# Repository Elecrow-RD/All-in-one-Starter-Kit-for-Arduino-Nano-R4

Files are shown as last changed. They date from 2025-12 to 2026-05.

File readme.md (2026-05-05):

## Menu
### 1, Product picture
### 2, Product version number
### 3, product information
### 4, Use the driver module
### 5,Quick Start
### 6,Folder structure.
### 7,Pin definition

### 1, Product picture

Crowpanel Advance ESP32 HMI AI Display

#### 2, Product version number

| | Hardware | Software | Remark |
| ---- | --- | --- | --- |
| 1 | V1.0 | V1.0 | latest |

### 3, product information

| Main Processor | Arduino NANO R4 |
| --- | --- |
| CPU/SoC | RA4M1(Arm® Cortex-M4®) |
| System memory | RAM32KB |
| Storage | Flash 256 kB |
| Bluetooth | None |
| WiFi | None |
| Interface | TYPE-C interface, I/O pins/sockets, Crowtail interface |
| Button | Reset |
| LED indicator light | Reset indicator light, power indicator light |
| Power input | 5V input charging |
| Shell material | PP (non-toxic) |
| Size | 195\*170*46（mm） |
| Net Weight | 415g |
| Operating temperature | 0°C to 60°C |
| Storage temperature | 0°C to 60°C |

### 4, Use the driver module

| Name | dependency library |
| --- | --- |
| IRremote | Arduino-IRremote-master <br />version: 4.5.0 |
| LSM6DS3  | Arduino_LSM6DS3-master<br />version=1.0.3 |
| BH1750 | BH1750<br />version: 1.3.0 |

### 5,Quick Start
### Arduino IDE starts

1.Download the library files used by this product to the 'libraries' folder.

C:\Users\Documents\Arduino\libraries\



2.Install the NANO R4 development board and open the program files

Arduino_NANO_R4-2

3.Open the code configuration environment and burn it

Arduino_NANO_R4-4

### 6,Folder structure.

|--Eagle_SCH&PCB: Contains **Eagle CAD** schematic (`.sch`) and PCB layout (`.brd`) files. These are used for circuit design and PCB manufacturing.

|--lesson_code: Provides  code and projects to demonstrate how to use the hardware and libraries. These examples help users get started quickly.

|--libraries: Includes necessary libraries required for compiling and running the project. These libraries provide drivers and additional functionalities for the hardware.

### 7,Pin definition

#### Sensor / Module List

| No.  | Sensor / Module Name | Quantity | Notes | nano pin |
| ---- | --- | --- | --- | --- |
| 1 | Temperature & Humidity Sensor | 1 | | A4/SDA<br />A5/SCL<br />I2C  ADDRESS:0X38 |
| 2 | Button | 3 | | A3_KEY |
| 3 | Ultrasonic Ranging Sensor | 1 | | D7_US_ECHO<br />D6_US_TRIG |
| 4 | Light Sensor | 1 | | A4/SDA<br />A5/SCL<br />I2C  ADDRESS:0X5C |
| 5 | Linear Potentiometer | 1 | | A0_ROTARY |
| 6 | LED (Red + Yellow + Green) | 3 | Red + Yellow + Green | ~D5_LED_R<br />~D10_LED_Y<br />~D11_LED_G |
| 7 | Buzzer | 1 | | D3_BUZZER |
| 8 | LCD Display | 1 | | A4/SDA<br />A5/SCL<br />I2C  ADDRESS:0X27 |
| 9 | Infrared Remote | 1 | Includes remote controller | D2_IR_R |
| 10 | Relay Module | 1 | | D4_RELAY |
| 11 | Servo Motor | 1 | | D9_SERVO |
| 12 | Sound Sensor | 1 | | A1_SOUND |
| 13 | 3-Axis Accelerometer | 1 | | A4/SDA<br />A5/SCL<br />I2C  ADDRESS:0x6B (pin SDO is logic High) |
| 14 | PIR Motion Sensor | 1 | | A2_PIR |
| 15 | Soil Moisture Sensor | 1 | Separate probe, 4-wire connector | A7 |
| 16 | 4-Digit Display | 1 | | A4/SDA<br />A5/SCL<br />I2C  ADDRESS:0X70 |

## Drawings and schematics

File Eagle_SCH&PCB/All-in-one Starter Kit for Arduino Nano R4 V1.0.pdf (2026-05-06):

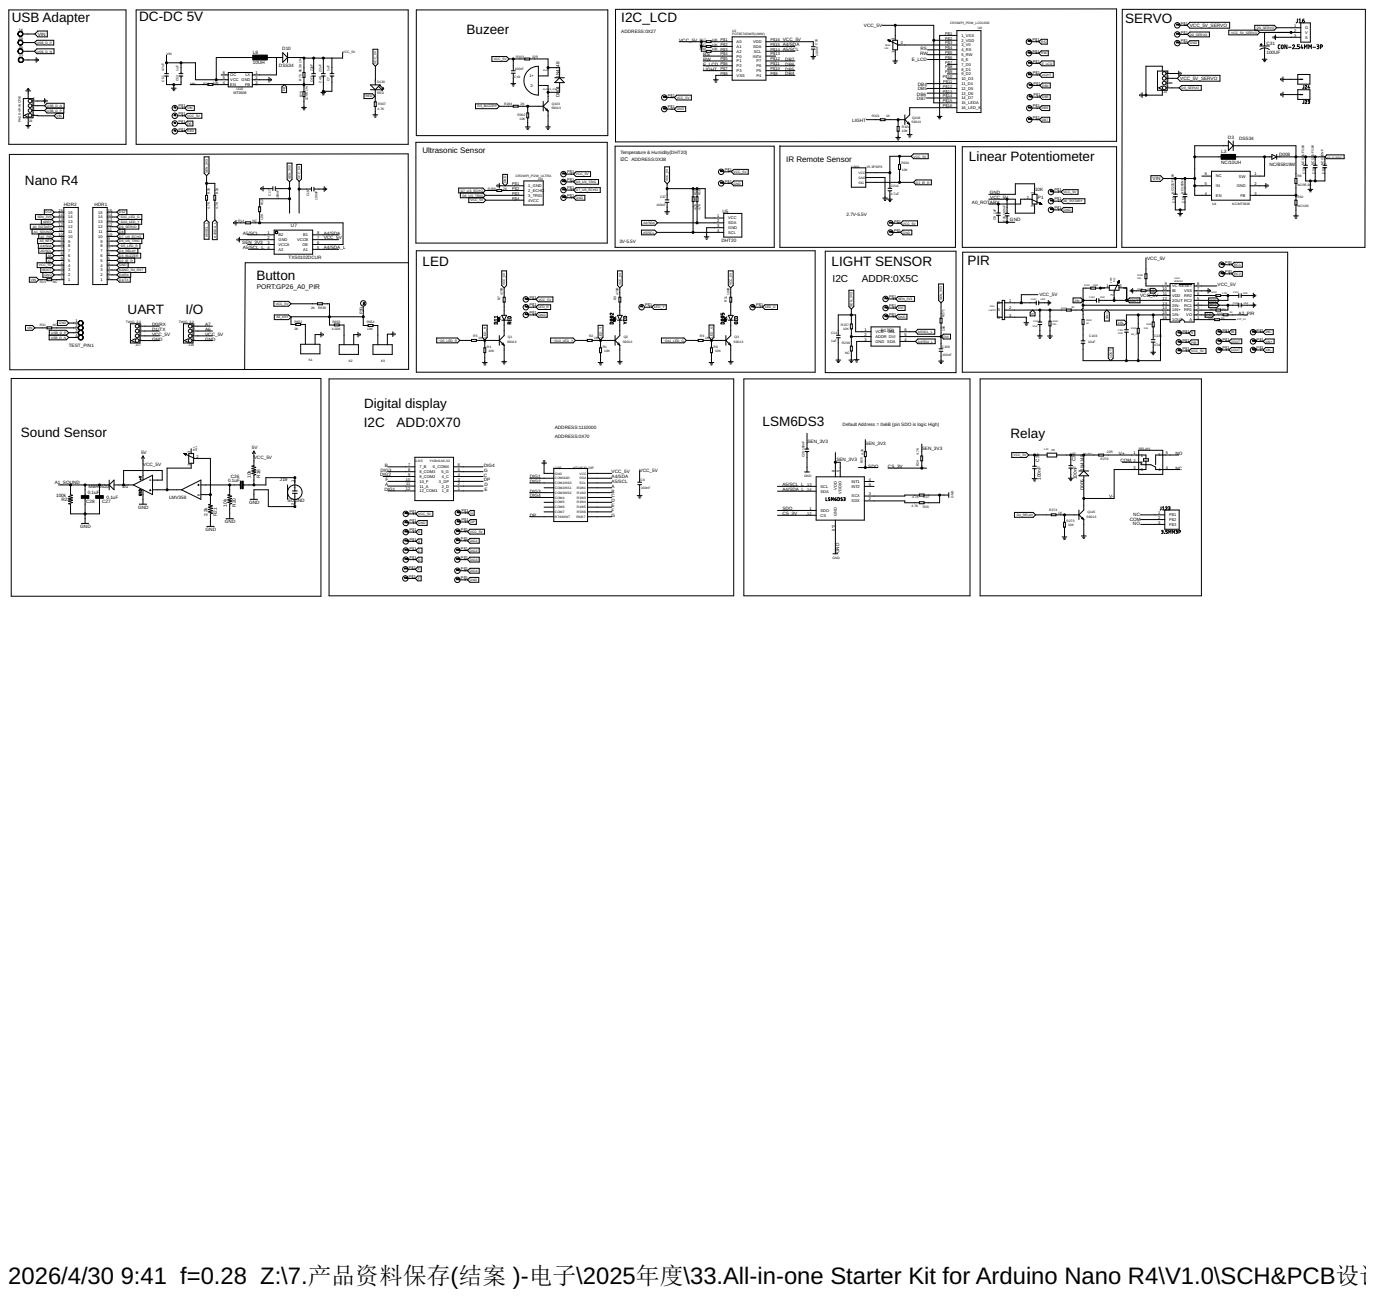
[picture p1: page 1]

2026/4/30 9:41 f=0.28 Z:\7.产品资料保存(结案 )-电子\2025年度\33.All-in-one Starter Kit for Arduino Nano R4\V1.0\SCH&PCB设计资料\V1.0\All-in-one Starter Kit for Arduino Nano R4 V1.0.sch (Sheet: 1/1)

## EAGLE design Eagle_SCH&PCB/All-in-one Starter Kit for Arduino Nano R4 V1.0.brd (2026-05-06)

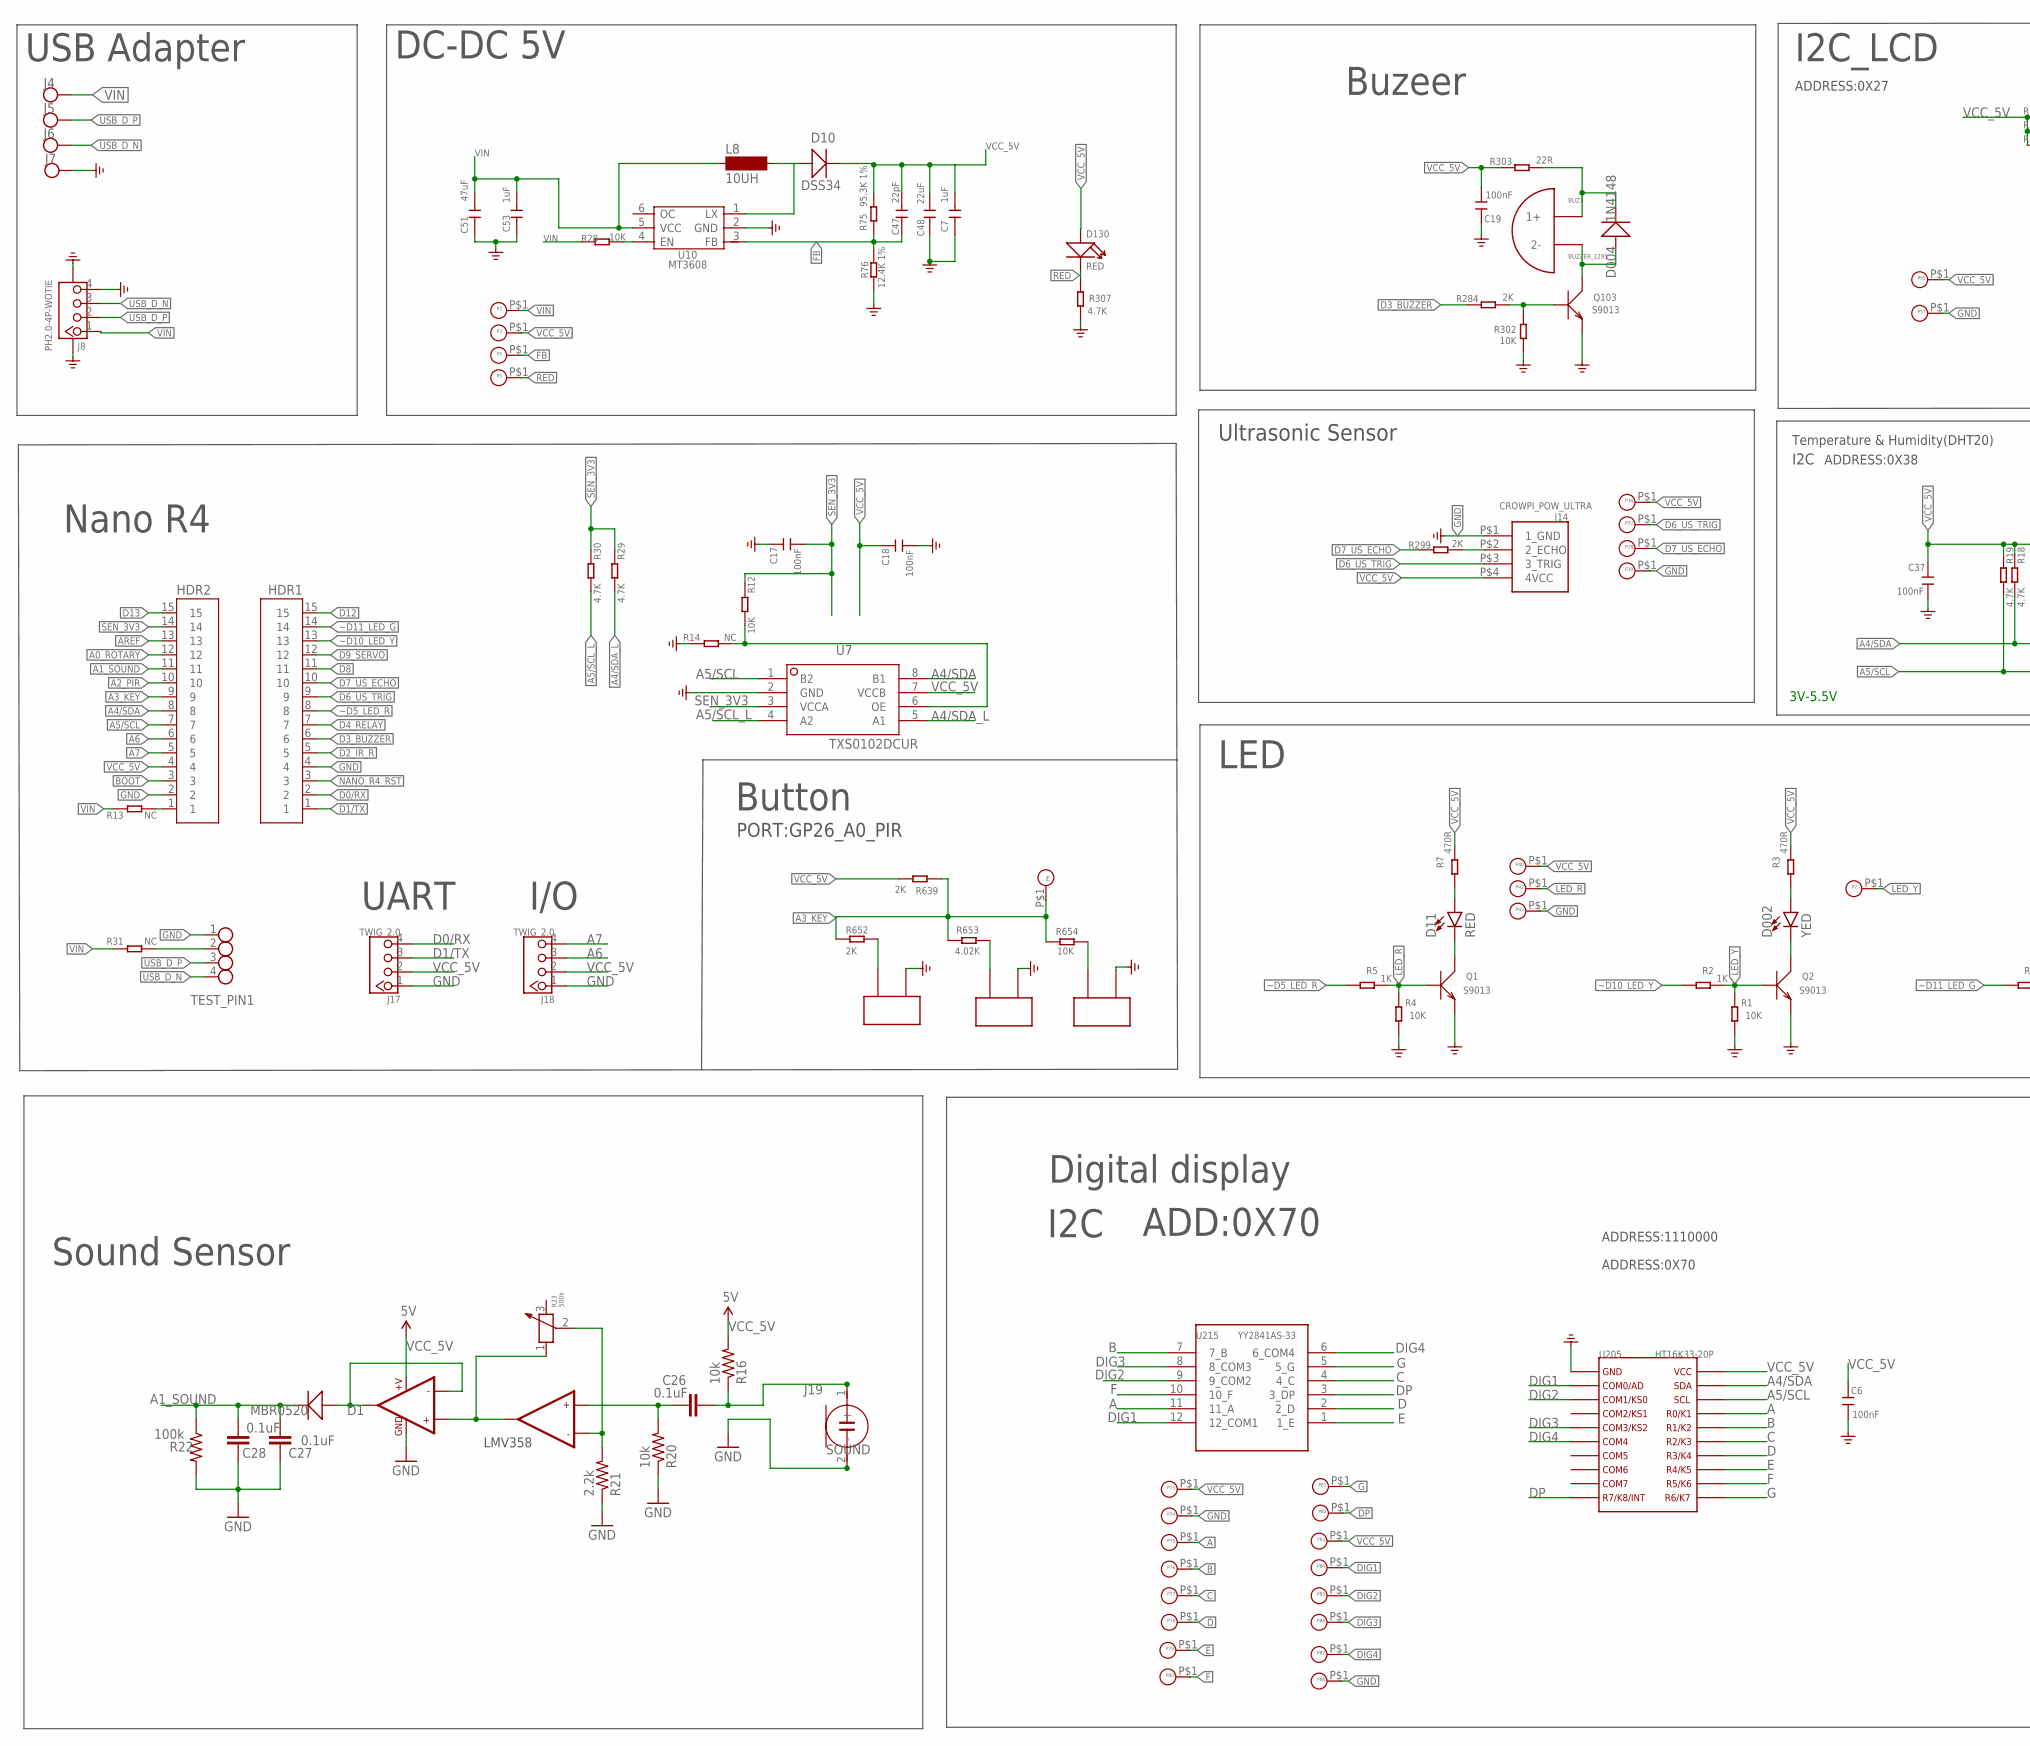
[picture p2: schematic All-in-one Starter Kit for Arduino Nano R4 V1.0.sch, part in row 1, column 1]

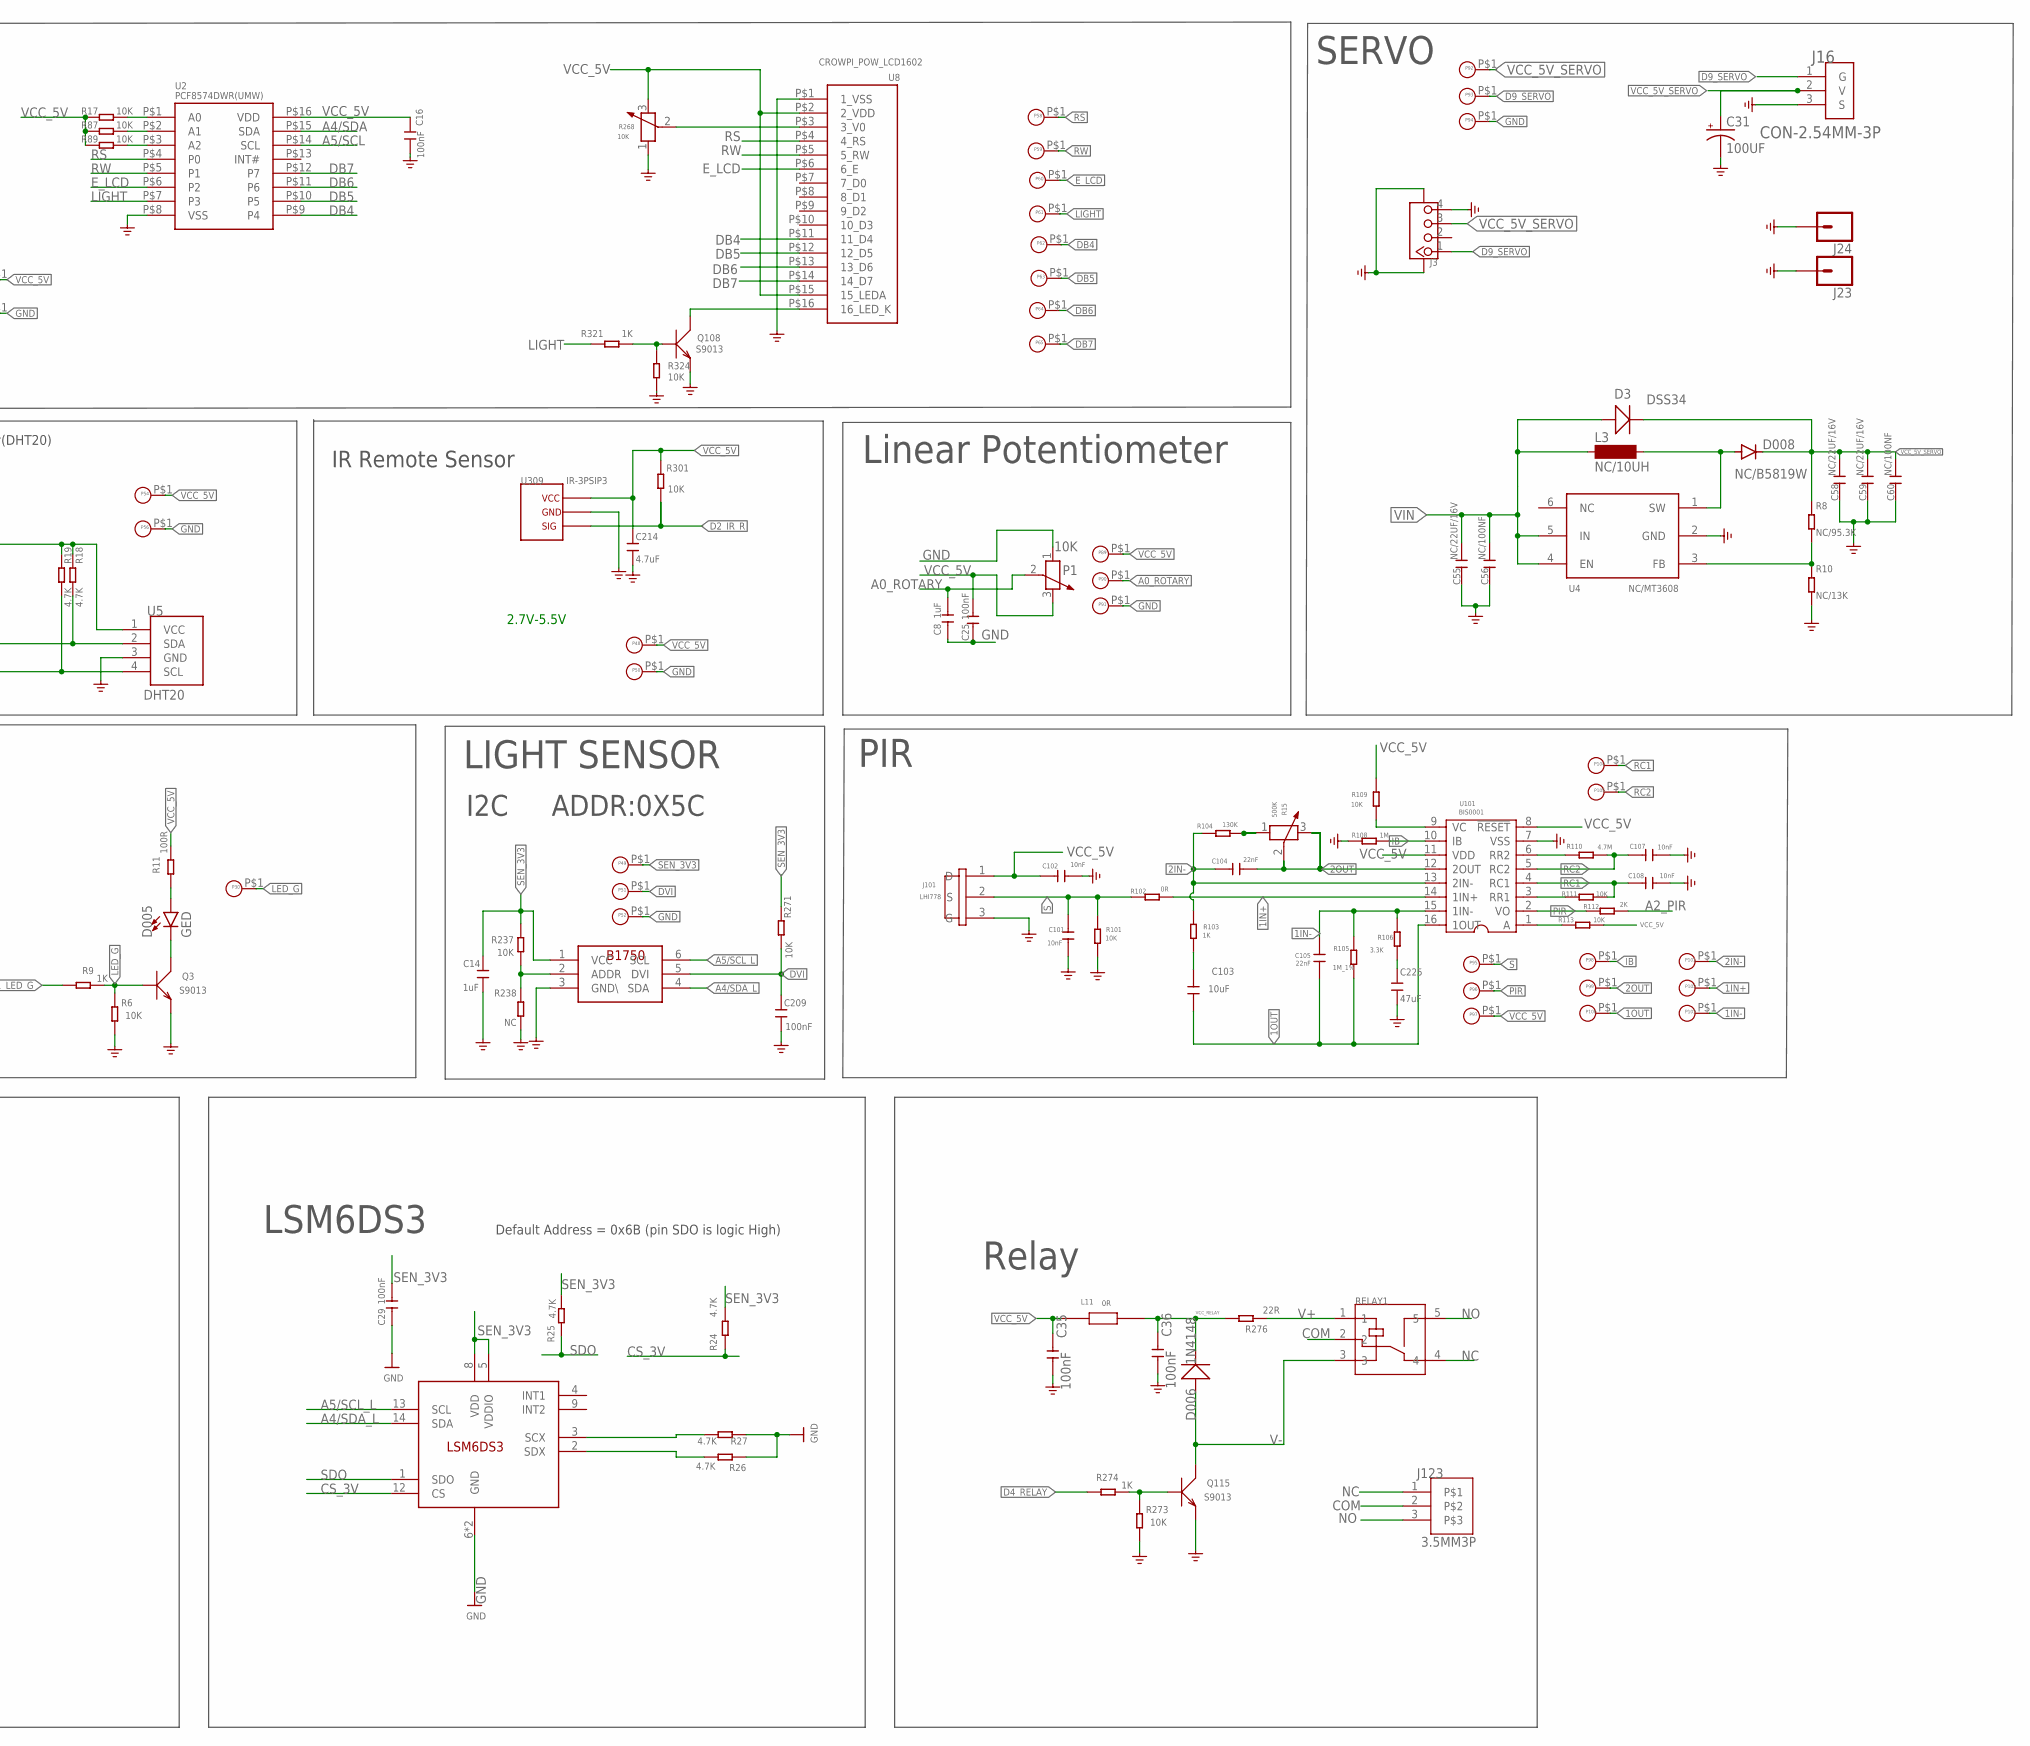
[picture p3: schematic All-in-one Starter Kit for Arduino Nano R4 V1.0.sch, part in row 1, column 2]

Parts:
BUZ1: BUZZER_1295; BUZZER-D12MM-DIP2
C6, C16, C17, C18, C19, C37, C209: 100nF; 0603
C7, C8, C53: 1uF; C0603
C14: 1uF; 0603
C25, C29, C35, C36: 100nF; C0603
C26, C27, C28: 0.1uF; 0603-CAP
C31: 100UF; SANYO-OSCON_SMD_C6
C47: 22pF; C0603
C48: 22uF; C0805
C51: 47uF; C0805
C55, C58, C59: NC/22UF/16V; C0603
C56, C60: NC/100NF; C0603
C101, C102, C107, C108: 10nF; C0603
C103: 10uF; 0603
C104, C105: 22nF; C0603
C214: 4.7uF; 0603
C225: 47uF; 0805
D1: MBR0520; SOD123-2.7X1.6
D002: YED; LED-8MM
D3, D10: DSS34; D_SOD123FL
D004, D006: 1N4148; D_SOD123
D005: GED; LED-8MM
D008: NC/B5819W; SOD-123_MINI-SMA
D11: RED; LED-8MM
D130: RED; LED_0603_SMT
HDR1, HDR2: KH-2.54FH-1X15P-H8.5; HDR-TH_15P-P2.54-V-F
J3: A_XBJ_CONNECTOR_TWIG-4P-2.0-SMD-FEMALE-REINFORCE9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; A_XBJ_CONNECTOR_4P-SMD-2.0-90D
J4, J5, J6, J7: TP-SMDTP-SMD-2X4MM; TP-SMD-2X4MM
J8: PH2.0-4P-WOTIE; PH2.0-4P
J14: CROWPI_POW_ULTRA
J16: CON-2.54MM-3P; CON-PZ-2.54MM-1*3P-WT
J17, J18: TWIG_2.0; 2.0_1X4
J19: SOUND; TEMPLATE_2P-D8.9MM
J23, J24: CONN_01_2.6MM1X01_2.6-4MM; 1X01_2.6MM
J101: LHI778; 3P-D8.1MM
J123: 3.5MM3P; 3.5MM*3P
K1, K2, K3: BUTTON_2P
L3: NC/10UH; MS42
L8: 10UH; MS42
L11: 0R; 201209
P1: 10K; 3P-SQUA-45.6X10X5.8H
P2, P3, P4, P5, P6, P7, P30, P36, P37, P38, P39, P40, P42, P43, P48, P49, P50, P51, P52, P54, P55, P56, P57, P58, P59, P60, P61, P62, P63, P64, P65, P73, P74, P75, P76, P77, P78, P79, P80, P81, P82, P83, P84, P85, P86, P87, P88, P89, P90, P91, P92, P93, P94, P95, P96, P97, P98, P99, P100, P101, P102, P103, P104, P105: PADPAD-1.0MM; PAD-1.0MM
Q1, Q2, Q3, Q103, Q108, Q115: S9013; SOT23@1
R1, R4, R6, R12, R17, R87, R89, R101, R109, R111, R113, R237, R271, R273, R301, R302, R324, R654: 10K; R0603
R2, R5, R9, R103, R274, R321: 1K; R0603
R3, R7: 470R; R0603
R8: NC/95.3K; R0603
R10: NC/13K; R0603
R11: 100R; R0603
R13, R14, R31, R238: NC; R0603
R15: 500K; 3P-SMD-SQUA-3.6X3.3
R16, R20: 10k; 0603-RES
R18, R19, R24, R25, R26, R27, R29, R30, R307: 4.7K; R0603
R21: 2.2k; 0603-RES
R22: 100k; 0603-RES
R23: 500k; 3P-SMD-SQUA-3.6X3.3
R28: 10K; R0603-SP
R75: 95.3K 1%; R0603-SP
R76: 12.4K 1%; R0603-SP
R102: 0R; R0603
R104: 130K; R0603
R105: 1M_1%; R0603
R106: 3.3K; R0603
R108: 1M; R0603
R110: 4.7M; R0603
R112, R284, R299, R639, R652: 2K; R0603
R268: 10K; 3P-SMD-SQUA-3.6X3.3
R276, R303: 22R; R0603
R653: 4.02K; R0603
RELAY1: RELAY-SRD; REY5-6-19.1X15.5X15.3MM
TEST_PIN1: POGOPIN_4
U1: BH1750; BH1750-WSOF-6
U2: PCF8574DWR(UMW); SO-16-300MIL
U3: LSM6DS3; LGA-14L
U4: NC/MT3608; DBV_R-PDSO-G6
U5: DHT20; CROWTAIL-DHT20-V1.0-20211013_DHT20
U6: LMV358; SO08
U7: TXS0102DCUR; VSSOP-8
U8: CROWPI_POW_LCD1602; CROWPI_POW_LCD1206
U10: MT3608; SOT23-6L
U101: BIS0001; SOP16
U205: HT16K33-20P; HT16K33-SOP20
U215: YY2841AS-33; 4-DIGITAL_DISPLAY
U309: IR-3PSIP3; VS1838B-SIP3

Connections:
1IN+: P102.P$1, R102.1, U101.14 (1IN+)
1IN-: C105.2, P103.P$1, R105.2, R106.2, U101.15 (1IN-)
1OUT: C103.2, C105.1, P100.P$1, R105.1, U101.16 (1OUT)
2IN-: C104.1, P101.P$1, R103.2, R104.2, U101.13 (2IN-)
2OUT: C104.2, P99.P$1, R15.2 (3), R15.3 (2), U101.12 (2OUT)
A: P75.P$1, U205.P$17, U215.11 (11_A)
A0_ROTARY: C8.2, HDR2.12, P1.2 (3), P90.P$1
A1_SOUND: C27.2, C28.2, D1.2 (-), HDR2.11, R22.1
A2_PIR: HDR2.10, R112.1
A3_KEY: HDR2.9, P6.P$1, R639.2, R652.2, R653.2, R654.2
A4/SDA: HDR2.8, R18.2, U2.P$15 (SDA), U5.2 (SDA), U7.8 (B1), U205.P$19
A4/SDA_L: R29.2, U1.4 (SDA), U3.14 (SDA), U7.5 (A1)
A5/SCL: HDR2.7, R19.2, U2.P$14 (SCL), U5.4 (SCL), U7.1 (B2), U205.P$18
A5/SCL_L: R30.2, U1.6 (SCL), U3.13 (SCL), U7.4 (A2)
A6: HDR2.6, J18.3
A7: HDR2.5, J18.4
AREF: HDR2.13
B: P76.P$1, U205.P$16, U215.7 (7_B)
BOOT: HDR2.3
C: P77.P$1, U205.P$15, U215.4 (4_C)
COM: J123.2, RELAY1.2
CS_3V: R24.1, U3.12 (CS)
D: P78.P$1, U205.P$14, U215.2 (2_D)
D0/RX: HDR1.2, J17.4
D1/TX: HDR1.1, J17.3
D2_IR_R: HDR1.5, R301.2, U309.3
D3_BUZZER: HDR1.6, R284.1
D4_RELAY: HDR1.7, R274.2
D6_US_TRIG: HDR1.9, J14.P$3 (3_TRIG), P37.P$1
D7_US_ECHO: HDR1.10, P38.P$1, R299.2
D8: HDR1.11
D9_SERVO: HDR1.12, J3.1, J16.1 (G), P93.P$1
D12: HDR1.15
D13: HDR2.15
DB4: P62.P$1, U2.P$9 (P4), U8.P$11 (11_D4)
DB5: P63.P$1, U2.P$10 (P5), U8.P$12 (12_D5)
DB6: P64.P$1, U2.P$11 (P6), U8.P$13 (13_D6)
DB7: P65.P$1, U2.P$12 (P7), U8.P$14 (14_D7)
DIG1: P84.P$1, U205.P$2, U215.12 (12_COM1)
DIG2: P85.P$1, U205.P$3, U215.9 (9_COM2)
DIG3: P86.P$1, U205.P$5, U215.8 (8_COM3)
DIG4: P87.P$1, U205.P$6, U215.6 (6_COM4)
DP: P82.P$1, U205.P$10, U215.3 (3_DP)
DVI: C209.2, P51.P$1, R271.2, U1.5 (DVI)
E: P79.P$1, U205.P$13, U215.1 (1_E)
E_LCD: P60.P$1, U2.P$6 (P2), U8.P$6 (6_E)
F: P80.P$1, U205.P$12, U215.10 (10_F)
FB: C47.2, P4.P$1, R75.1, R76.2, U10.3 (FB)
G: P81.P$1, U205.P$11, U215.5 (5_G)
GND: C6.1, C7.1, C8.1, C14.1, C16.1, C17.2, C18.1, C19.2, C25.1, C27.1, C28.1, C29.1, C31.-, C35.1, C36.1, C37.1, C48.1, C51.1, C53.1, C55.1, C56.1, C58.1, C59.1, C60.1, C101.1, C102.1, C107.2, C108.2, C209.1, C214.1, C225.1, HDR1.4, HDR2.2, J3.4, J3.SS1, J3.SS2, J7.1, J8.4, J8.5 (SS1), J8.6 (SS2), J14.P$1 (1_GND), J16.3 (S), J17.1, J18.1, J19.2 (-), J23.1, J24.1, J101.3 (G), K1.P$1, K2.P$1, K3.P$1, P1.1, P39.P$1, P43.P$1, P50.P$1, P52.P$1, P56.P$1, P57.P$1, P74.P$1, P88.P$1, P91.P$1, P94.P$1, Q1.2 (E), Q2.2 (E), Q3.2 (E), Q103.2 (E), Q108.2 (E), Q115.2 (E), R1.1, R4.1, R6.1, R10.2, R14.1, R20.1, R21.1, R22.2, R26.1, R27.1, R76.1, R101.1, R108.1, R238.1, R268.1, R273.1, R302.1, R307.2, R324.2, TEST_PIN1.1, U1.3 (GND\), U2.P$8 (VSS), U3.6 (GND), U3.7 (GND), U4.2 (GND), U5.3 (GND), U6.4 (GND), U7.2 (GND), U8.P$1 (1_VSS), U10.2 (GND), U101.7 (VSS), U205.P$1, U309.2
IB: P98.P$1, R108.2, U101.10 (IB)
LED_G: P30.P$1, Q3.1 (B), R6.2, R9.1
LED_R: P42.P$1, Q1.1 (B), R4.2, R5.1
LED_Y: P7.P$1, Q2.1 (B), R1.2, R2.1
LIGHT: P61.P$1, R321.2, U2.P$7 (P3)
unnamed: R111.1, U101.3 (RR1)
unnamed: Q108.1 (B), R321.1, R324.1
unnamed: C225.2, R106.1
unnamed: D10.+, L8.2, U10.1 (LX)
unnamed: D002.2 (C), Q2.3 (C)
unnamed: R28.2, U10.4 (EN)
unnamed: R268.2 (3), U8.P$3 (3_V0)
unnamed: D002.1 (A), R3.2
unnamed: D005.2 (C), Q3.3 (C)
unnamed: R17.2, U2.P$1 (A0)
unnamed: R87.2, U2.P$2 (A1)
unnamed: R89.2, U2.P$3 (A2)
unnamed: D008.A, L3.2, U4.1 (SW)
unnamed: D005.1 (A), R11.2
unnamed: D11.2 (C), Q1.3 (C)
unnamed: D11.1 (A), R7.2
unnamed: R31.1, TEST_PIN1.2
unnamed: HDR2.1, R13.1
unnamed: Q108.3 (C), U8.P$16 (16_LED_K)
unnamed: R12.2, R14.2, U7.6 (OE)
unnamed: R110.2, U101.6 (RR2)
unnamed: R109.2, U101.9 (VC)
unnamed: C103.1, R103.1
unnamed: R8.2, R10.1, U4.3 (FB)
unnamed: R113.2, U101.1 (A)
unnamed: R15.1, R104.1
unnamed: C26.1, J19.1 (+), R16.1
unnamed: C26.2, R20.2, U6.5 (+IN2)
unnamed: R21.2, R23.2 (3), U6.6 (-IN2)
unnamed: D1.1 (+), U6.1 (OUT1), U6.2 (-IN1)
unnamed: R23.1, U6.3 (+IN1), U6.7 (OUT2)
unnamed: R26.2, U3.2 (SDX)
unnamed: R27.2, U3.3 (SCX)
unnamed: K1.P$2, R652.1
unnamed: K2.P$2, R653.1
unnamed: K3.P$2, R654.1
unnamed: R237.1, R238.2, U1.2 (ADDR)
unnamed: Q115.1 (B), R273.2, R274.1
unnamed: J14.P$2 (2_ECHO), R299.1
unnamed: Q103.1 (B), R284.2, R302.2
unnamed: BUZ1.2 (2-), D004.+, Q103.3 (C)
unnamed: BUZ1.1 (1+), D004.-, R303.2
NANO_R4_RST: HDR1.3
NC: J123.1, RELAY1.4
NO: J123.3, RELAY1.5
PIR: P96.P$1, R112.2, U101.2 (VO)
RC1: C108.1, P104.P$1, R111.2, U101.4 (RC1)
RC2: C107.1, P105.P$1, R110.1, U101.5 (RC2)
RED: D130.2 (2_K), P5.P$1, R307.1
RS: P58.P$1, U2.P$4 (P0), U8.P$4 (4_RS)
RW: P59.P$1, U2.P$5 (P1), U8.P$5 (5_RW)
S: C101.2, J101.2 (S), P95.P$1, R101.2, R102.2
SDO: R25.1, U3.1 (SDO)
SEN_3V3: C14.2, C17.1, C29.2, HDR2.14, P49.P$1, R12.1, R24.2, R25.2, R29.1, R30.1, R237.2, R271.1, U1.1 (VCC), U3.5 (VDDIO), U3.8 (VDD), U7.3 (VCCA)
USB_D_N: J6.1, J8.3, TEST_PIN1.4
USB_D_P: J5.1, J8.2, TEST_PIN1.3
V+: R276.2, RELAY1.1
V-: D006.+, Q115.3 (C), RELAY1.3
VCC_5V: C6.2, C7.2, C16.2, C18.2, C19.1, C25.2, C35.2, C37.2, C47.1, C48.2, C102.2, C214.2, D10.-, D130.1 (1_A), HDR2.4, J14.P$4 (4VCC), J17.2, J18.2, J101.1 (D), L11.1, P1.3 (2), P3.P$1, P36.P$1, P40.P$1, P48.P$1, P54.P$1, P55.P$1, P73.P$1, P83.P$1, P89.P$1, P97.P$1, R3.1, R7.1, R11.1, R16.2, R17.1, R18.1, R19.1, R75.2, R87.1, R89.1, R109.1, R113.1, R268.3 (2), R301.1, R303.1, R639.1, U2.P$16 (VDD), U5.1 (VCC), U6.8 (+V), U7.7 (VCCB), U8.P$2 (2_VDD), U8.P$15 (15_LEDA), U101.8 (!RESET), U101.11 (VDD), U205.P$20, U309.1
VCC_5V_SERVO: C31.+, C58.2, C59.2, C60.2, D3.-, D008.C, J3.3, J16.2 (V), P92.P$1, R8.1
VCC_RELAY: C36.2, D006.-, L11.2, R276.1
VIN: C51.2, C53.2, C55.2, C56.2, D3.+, J4.1, J8.1, L3.1, L8.1, P2.P$1, R13.2, R28.1, R31.2, U4.4 (EN), U4.5 (IN), U10.5 (VCC)
~D5_LED_R: HDR1.8, R5.2
~D10_LED_Y: HDR1.13, R2.2
~D11_LED_G: HDR1.14, R9.2

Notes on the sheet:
I2C_LCD
LIGHT SENSOR
SERVO
Ultrasonic Sensor
IR Remote Sensor
I2C
Temperature & Humidity(DHT20)
PIR
2.7V-5.5V
3V-5.5V
ADDRESS:0X38
ADDRESS:0X27
LED
Linear Potentiometer
DC-DC 5V
USB Adapter
ADDR:0X5C
Nano R4
Digital display
ADDRESS:0X70
ADDRESS:1110000
ADD:0X70
UART
I/O
Buzeer
Default Address = 0x6B (pin SDO is logic High)
LSM6DS3
Sound Sensor
LMV358
Relay
Button
PORT:GP26_A0_PIR

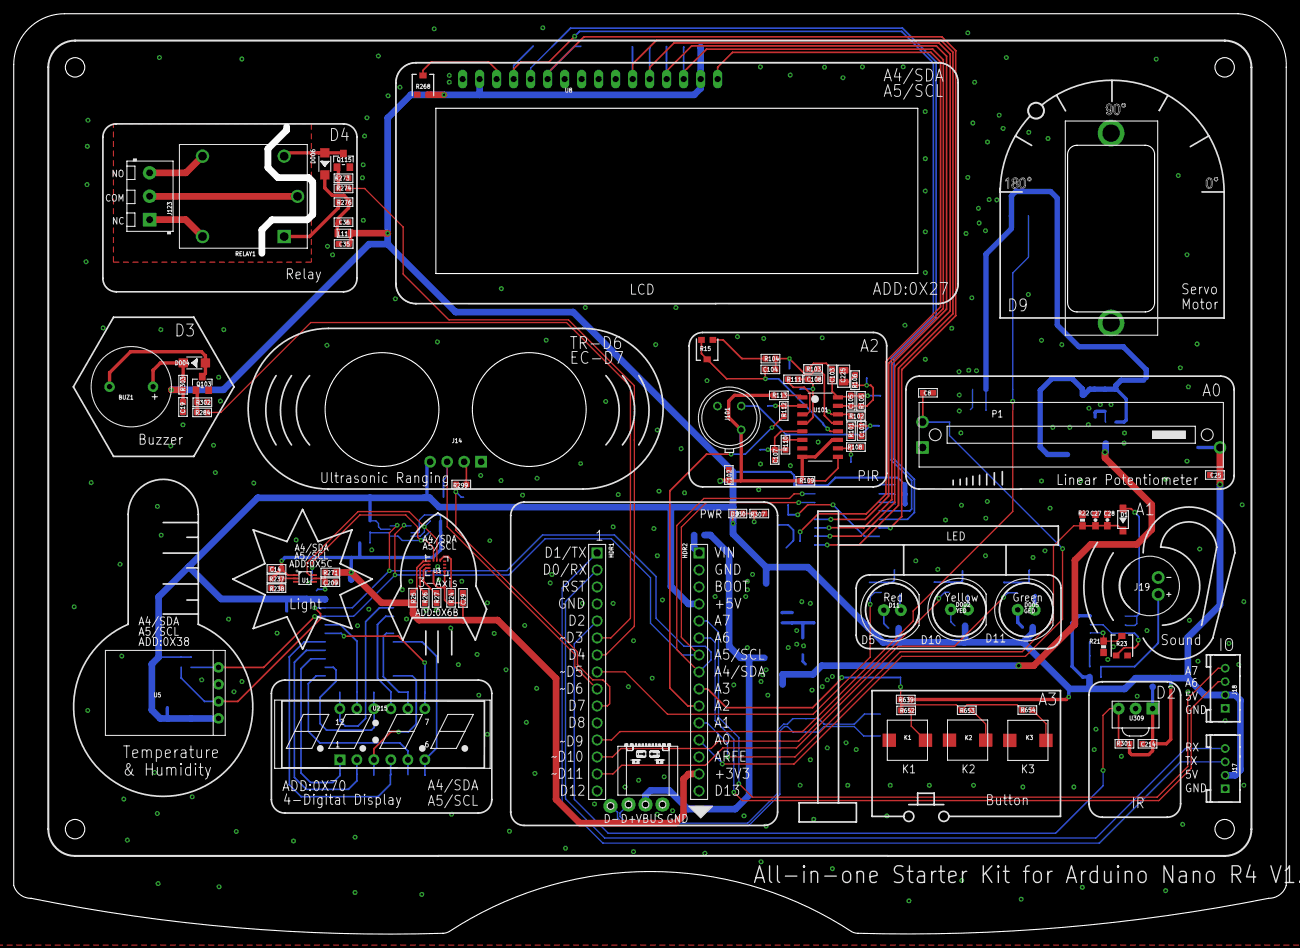
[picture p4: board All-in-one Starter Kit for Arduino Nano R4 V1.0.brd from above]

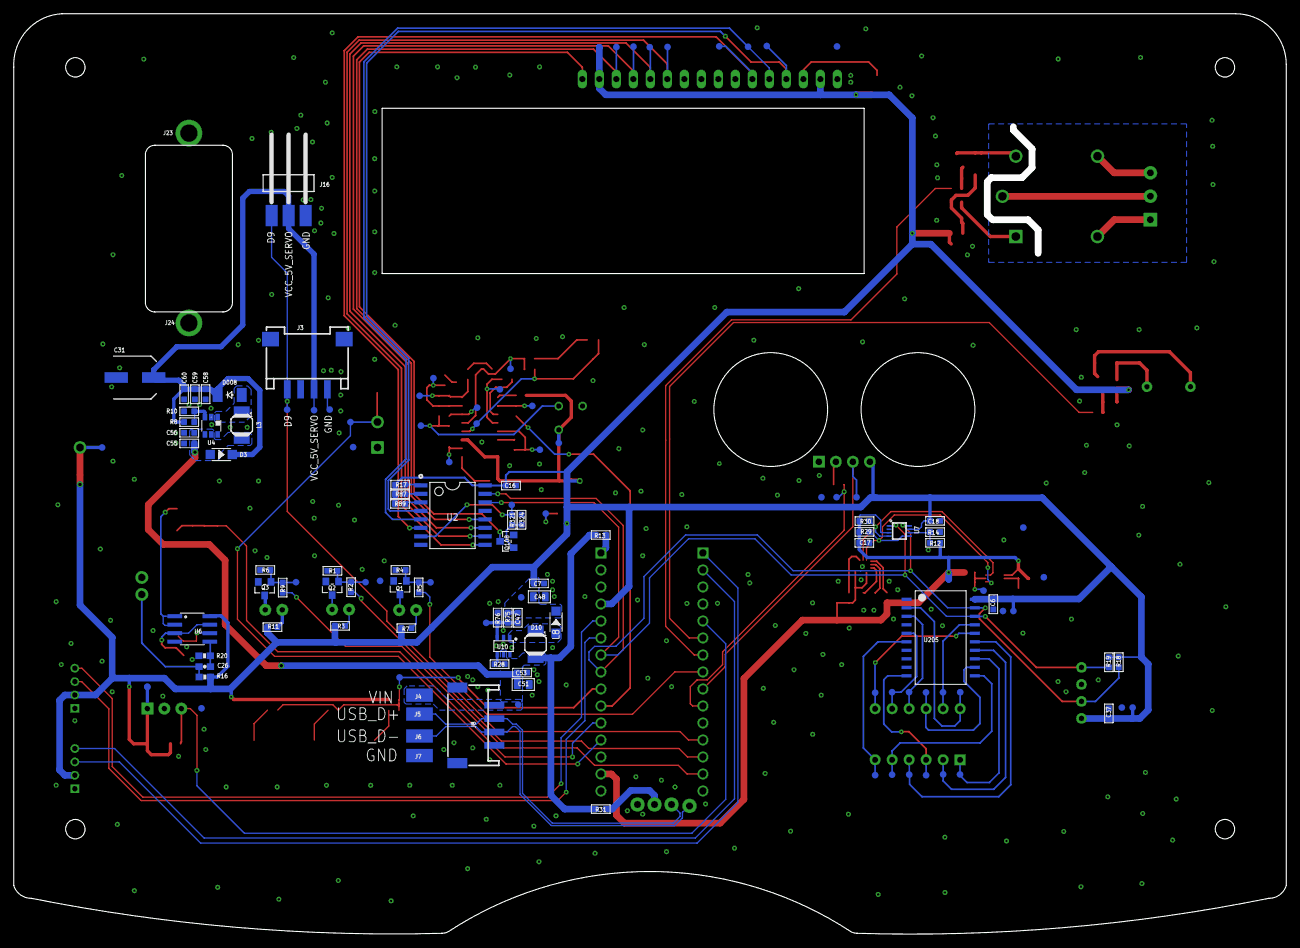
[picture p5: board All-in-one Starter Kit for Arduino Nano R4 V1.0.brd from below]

Board: 2 copper layers, 190.1 x 137.5 mm, 222 parts (134 on the bottom side), 114 nets.

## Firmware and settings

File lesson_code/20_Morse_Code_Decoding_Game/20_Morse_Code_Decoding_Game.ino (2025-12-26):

#include <Wire.h>
#include <LiquidCrystal_I2C.h>

/*
  =================== Hardware Definitions ===================
*/

// LED pin definitions
#define LED_RED     5
#define LED_YELLOW  10
#define LED_GREEN   11

// All three buttons share one analog input pin
#define BUTTON_ANALOG A3

/*
  =================== LCD Parameters ===================
*/
#define COLUMNS 16   // Number of LCD columns
#define ROWS    2    // Number of LCD rows

// Create an LCD object using PCF8574 I2C expander
LiquidCrystal_I2C lcd(
  PCF8574_ADDR_A21_A11_A01,  // I2C address of PCF8574
  4, 5, 6, 16,              // RS, RW, EN, Backlight
  11, 12, 13, 14,           // D4, D5, D6, D7
  POSITIVE                  // Backlight polarity
);

/*
  =================== Morse Code Table ===================
  Index corresponds to letters A–Z
*/
const char* morseCodes[] = {
  ".-",    // A
  "-...",  // B
  "-.-.",  // C
  "-..",   // D
  ".",     // E
  "..-.",  // F
  "--.",   // G
  "....",  // H
  "..",    // I
  ".---",  // J
  "-.-",   // K
  ".-..",  // L
  "--",    // M
  "-.",    // N
  "---",   // O
  ".--.",  // P
  "--.-",  // Q
  ".-.",   // R
  "...",   // S
  "-",     // T
  "..-",   // U
  "...-",  // V
  ".--",   // W
  "-..-",  // X
  "-.--",  // Y
  "--.."   // Z
};

// Corresponding alphabet characters
const char letters[] = "ABCDEFGHIJKLMNOPQRSTUVWXYZ";

/*
  =================== Timing & Threshold Parameters ===================
*/
const int SHORT_PRESS_THRESHOLD = 500;     // Short press < 500ms → dot
const int CHAR_INTERVAL = 1500;            // Idle time to auto-decode a character
const int CLEAR_SCREEN_THRESHOLD = 1000;   // Long press > 1s → clear screen
const int BLINK_INTERVAL = 200;             // LED blink interval (ms)

/*
  =================== Analog Button Ranges ===================
  (Must match your resistor ladder hardware)
*/
const int MORSE_BTN_RANGE[2]  = {500, 520};  // Morse input button
const int SPACE_BTN_RANGE[2]  = {680, 690};  // Space button
const int DELETE_BTN_RANGE[2] = {845, 860};  // Delete / clear button

/*
  =================== Global Variables ===================
*/
String currentMorse = "";   // Current Morse sequence being entered
String displayText  = "";   // Full text displayed on LCD (history preserved)

unsigned long buttonPressTime = 0;         // Timestamp when a button is pressed
unsigned long lastButtonReleaseTime = 0;  // Timestamp of last button release

bool morseBtnPressed  = false;   // Morse button state
bool spaceBtnPressed  = false;   // Space button state
bool deleteBtnPressed = false;   // Delete button state

/*
  =================== Function Declarations ===================
*/
char decodeMorse(String morse);
void resetMorseInput();
void updateLCDDisplay();
void blinkRedLED(int times);

/*
  =================== Setup Function ===================
*/
void setup() {
  Serial.begin(115200);   // Initialize serial communication for debugging

  // Initialize LED pins
  pinMode(LED_RED, OUTPUT);
  pinMode(LED_YELLOW, OUTPUT);
  pinMode(LED_GREEN, OUTPUT);

  // Initialize LCD
  lcd.begin(COLUMNS, ROWS, LCD_5x8DOTS);
  lcd.clear();
  lcd.backlight();

  // Startup message
  lcd.setCursor(0, 0);
  lcd.print(F("Morse Decoder"));
  lcd.setCursor(0, 1);
  lcd.print(F("Ready"));

  delay(1500);
  lcd.clear();
}

/*
  =================== Main Loop ===================
*/
void loop() {
  // Read the shared analog button value
  int val = analogRead(BUTTON_ANALOG);

  // Handle each button based on analog value
  handleMorseButton(val);
  handleSpaceButton(val);
  handleDeleteButton(val);

  delay(10);  // Simple debounce delay
}

/*
  =================== Morse Input Button ===================
  Short press → dot
  Long press  → dash
*/
void handleMorseButton(int val) {
  bool active = (val >= MORSE_BTN_RANGE[0] && val <= MORSE_BTN_RANGE[1]);

  // Button pressed
  if (active && !morseBtnPressed) {
    morseBtnPressed = true;
    buttonPressTime = millis();
    digitalWrite(LED_YELLOW, HIGH);  // Yellow LED indicates button hold
  }
  // Button released
  else if (!active && morseBtnPressed) {
    morseBtnPressed = false;
    digitalWrite(LED_YELLOW, LOW);

    unsigned long duration = millis() - buttonPressTime;
    lastButtonReleaseTime = millis();

    // Determine dot or dash
    if (duration < SHORT_PRESS_THRESHOLD) {
      currentMorse += ".";
      digitalWrite(LED_GREEN, HIGH);
    } else {
      currentMorse += "-";
      digitalWrite(LED_RED, HIGH);
    }

    delay(100);
    digitalWrite(LED_GREEN, LOW);
    digitalWrite(LED_RED, LOW);
  }

  // Auto-decode if idle timeout reached
  if (!active && currentMorse.length() > 0) {
    if (millis() - lastButtonReleaseTime > CHAR_INTERVAL) {
      char c = decodeMorse(currentMorse);
      displayText += c;
      updateLCDDisplay();
      resetMorseInput();
    }
  }
}

/*
  =================== Space Button ===================
  Adds a space character
*/
void handleSpaceButton(int val) {
  bool active = (val >= SPACE_BTN_RANGE[0] && val <= SPACE_BTN_RANGE[1]);

  if (active && !spaceBtnPressed) {
    spaceBtnPressed = true;
    digitalWrite(LED_GREEN, HIGH);  // Green LED indicates space key
  }
  else if (!active && spaceBtnPressed) {
    spaceBtnPressed = false;
    digitalWrite(LED_GREEN, LOW);

    displayText += " ";
    updateLCDDisplay();
    delay(100);
  }
}

/*
  =================== Delete Button ===================
  Short press → delete last character
  Long press  → clear screen
*/
void handleDeleteButton(int val) {
  bool active = (val >= DELETE_BTN_RANGE[0] && val <= DELETE_BTN_RANGE[1]);

  if (active && !deleteBtnPressed) {
    deleteBtnPressed = true;
    buttonPressTime = millis();
    digitalWrite(LED_RED, HIGH);
  }
  else if (deleteBtnPressed) {
    unsigned long pressTime = millis() - buttonPressTime;

    // Long press: clear entire display
    if (pressTime >= CLEAR_SCREEN_THRESHOLD) {
      displayText = "";
      lcd.clear();
      blinkRedLED(3);
      deleteBtnPressed = false;
      digitalWrite(LED_RED, LOW);
    }
    // Short press: delete last character
    else if (!active) {
      if (displayText.length() > 0) {
        displayText.remove(displayText.length() - 1);
        updateLCDDisplay();
      }
      deleteBtnPressed = false;
      digitalWrite(LED_RED, LOW);
      delay(100);
    }
  }
}

/*
  =================== Utility Functions ===================
*/

// Convert Morse code string to corresponding letter
char decodeMorse(String morse) {
  for (int i = 0; i < 26; i++) {
    if (morse == morseCodes[i]) return letters[i];
  }
  return '?';  // Unknown Morse sequence
}

// Reset current Morse input state
void resetMorseInput() {
  currentMorse = "";
  lastButtonReleaseTime = millis();
}

// Update LCD display while preserving text history
void updateLCDDisplay() {
  lcd.clear();
  if (displayText.length() <= COLUMNS) {
    lcd.setCursor(0, 0);
    lcd.print(displayText);
  } else {
    lcd.setCursor(0, 0);
    lcd.print(displayText.substring(0, COLUMNS));
    lcd.setCursor(0, 1);
    lcd.print(displayText.substring(COLUMNS));
  }
}

// Blink the red LED a given number of times
void blinkRedLED(int times) {
  for (int i = 0; i < times; i++) {
    digitalWrite(LED_RED, HIGH);
    delay(BLINK_INTERVAL);
    digitalWrite(LED_RED, LOW);
    delay(BLINK_INTERVAL);
  }
}

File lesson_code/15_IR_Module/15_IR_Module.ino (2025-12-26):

#include <DIYables_IRcontroller.h>              // Include the DIYables IR controller library

#define IR_RECEIVER_PIN 2                       // Define the Arduino pin connected to the IR receiver

DIYables_IRcontroller_21 irController(          // Create an IR controller object for a 21-key remote
  IR_RECEIVER_PIN,                              // Specify the pin used by the IR receiver
  200                                           // Set debounce time to 200 milliseconds
);

void setup() {                                  // Arduino setup function, runs once
  Serial.begin(115200);                         // Initialize serial communication at 115200 baud rate
  irController.begin();                         // Initialize the IR controller
}

void loop() {                                   // Arduino loop function, runs repeatedly
  Key21 command = irController.getKey();         // Read the pressed key from the IR remote

  if (command != Key21::NONE) {                 // Check if a valid key was received
    switch (command) {                          // Determine which key was pressed

      case Key21::KEY_CH_MINUS:                 // If the CH- key is pressed
        Serial.println("CH-");                  // Print "CH-" to the serial monitor
        break;                                  // Exit the switch case

      case Key21::KEY_CH:                       // If the CH key is pressed
        Serial.println("CH");                   // Print "CH" to the serial monitor
        break;                                  // Exit the switch case

      case Key21::KEY_CH_PLUS:                  // If the CH+ key is pressed
        Serial.println("CH+");                  // Print "CH+" to the serial monitor
        break;                                  // Exit the switch case

      case Key21::KEY_PREV:                     // If the previous (<<) key is pressed
        Serial.println("<<");                   // Print "<<" to the serial monitor
        break;                                  // Exit the switch case

      case Key21::KEY_NEXT:                     // If the next (>>) key is pressed
        Serial.println(">>");                   // Print ">>" to the serial monitor
        break;                                  // Exit the switch case

      case Key21::KEY_PLAY_PAUSE:               // If the play/pause key is pressed
        Serial.println(">||");                  // Print ">||" to the serial monitor
        break;                                  // Exit the switch case

      case Key21::KEY_VOL_MINUS:                // If the volume down key is pressed
        Serial.println("-");                    // Print "-" to the serial monitor
        break;                                  // Exit the switch case

      case Key21::KEY_VOL_PLUS:                 // If the volume up key is pressed
        Serial.println("+");                    // Print "+" to the serial monitor
        break;                                  // Exit the switch case

      case Key21::KEY_EQ:                       // If the EQ key is pressed
        Serial.println("EQ");                   // Print "EQ" to the serial monitor
        break;                                  // Exit the switch case

      case Key21::KEY_100_PLUS:                 // If the 100+ key is pressed
        Serial.println("100+");                 // Print "100+" to the serial monitor
        break;                                  // Exit the switch case

      case Key21::KEY_200_PLUS:                 // If the 200+ key is pressed
        Serial.println("200+");                 // Print "200+" to the serial monitor
        break;                                  // Exit the switch case

      case Key21::KEY_0:                        // If the number 0 key is pressed
        Serial.println("0");                    // Print "0" to the serial monitor
        break;                                  // Exit the switch case

      case Key21::KEY_1:                        // If the number 1 key is pressed
        Serial.println("1");                    // Print "1" to the serial monitor
        break;                                  // Exit the switch case

      case Key21::KEY_2:                        // If the number 2 key is pressed
        Serial.println("2");                    // Print "2" to the serial monitor
        break;                                  // Exit the switch case

      case Key21::KEY_3:                        // If the number 3 key is pressed
        Serial.println("3");                    // Print "3" to the serial monitor
        break;                                  // Exit the switch case

      case Key21::KEY_4:                        // If the number 4 key is pressed
        Serial.println("4");                    // Print "4" to the serial monitor
        break;                                  // Exit the switch case

      case Key21::KEY_5:                        // If the number 5 key is pressed
        Serial.println("5");                    // Print "5" to the serial monitor
        break;                                  // Exit the switch case

      case Key21::KEY_6:                        // If the number 6 key is pressed
        Serial.println("6");                    // Print "6" to the serial monitor
        break;                                  // Exit the switch case

      case Key21::KEY_7:                        // If the number 7 key is pressed
        Serial.println("7");                    // Print "7" to the serial monitor
        break;                                  // Exit the switch case

      case Key21::KEY_8:                        // If the number 8 key is pressed
        Serial.println("8");                    // Print "8" to the serial monitor
        break;                                  // Exit the switch case

      case Key21::KEY_9:                        // If the number 9 key is pressed
        Serial.println("9");                    // Print "9" to the serial monitor
        break;                                  // Exit the switch case

      default:                                  // If the key is not recognized
        Serial.println("WARNING: undefined command:"); // Print a warning message
        break;                                  // Exit the switch case
    }
  }
}

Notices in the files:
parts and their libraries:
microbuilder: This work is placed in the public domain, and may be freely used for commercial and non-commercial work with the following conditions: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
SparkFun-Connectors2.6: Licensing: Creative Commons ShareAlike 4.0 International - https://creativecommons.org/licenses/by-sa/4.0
